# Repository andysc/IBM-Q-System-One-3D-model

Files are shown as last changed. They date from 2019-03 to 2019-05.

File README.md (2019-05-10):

# Quantum
3D-printed model of IBM Q System One

OpenSCAD model of a 1cm to 1foot scale model of the IBM Q System One Quantum Computer.

## Print list...
Set one of the control variables to *true* and all the others to *false* at the top of the model file to render each component in turn.

*black filament*
+ base
+ base_lid
+ back_box  * print with raft *  
+ top_box  
+ top_box_lid (inverted)   
+ lid (inverted)  
+ lid_lower (inverted)  
+ lid plinth (inverted for smoothness)   

*white filament*
+ reflector in white (inverted)  
+ reflector_strip in white

*translucent filament*
+ diffuser in clear filament (inverted)

Cryostat needs to be a 25mm x 44mm silver tube (I used chrome-plated wardrobe rail)

Glass walls in 1mm acrylic (2 of each size)  
front and back: 92 x 81 mm  
left and right: 85 x 81 mm

## Exploded view of the printed components

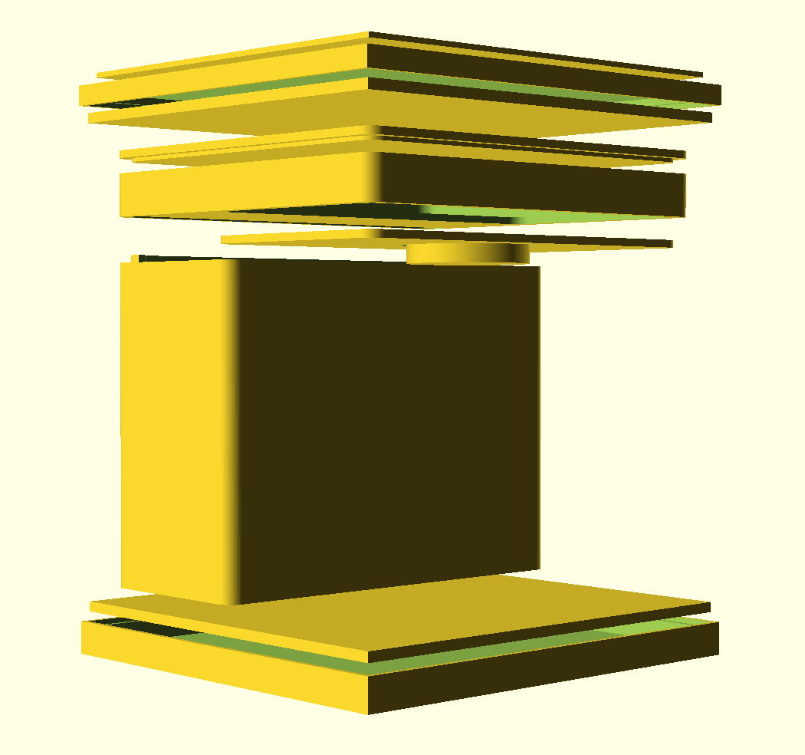
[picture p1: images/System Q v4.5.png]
exploded view


## The finished model

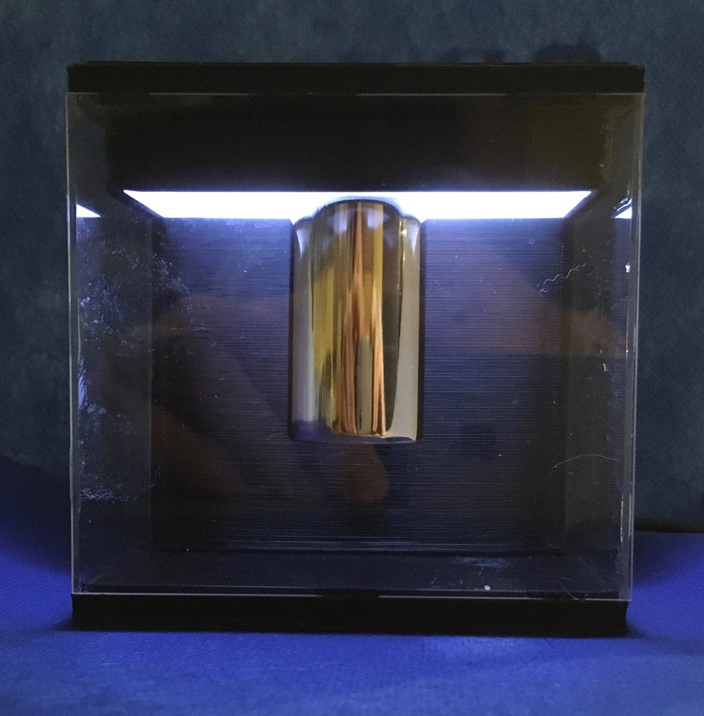
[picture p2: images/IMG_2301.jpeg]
IBM Q System One model


## Electronics

The top box has a row of 8 neopixels (144 leds/metre) inside, with a Wemos ESP-8266 Arduino (in the back box) controlling it via MQTT over WiFi. There's a cut-out for a micro-USB cable to come out through the back of the base.  

For information about how to connect a Wemos with Neopixels using MQTT, see @DrLucyRogers' excellent article here:
[Connect your IoT "Thing" to the Cloud](https://www.rs-online.com/designspark/content-types/project/13257?lang=en)

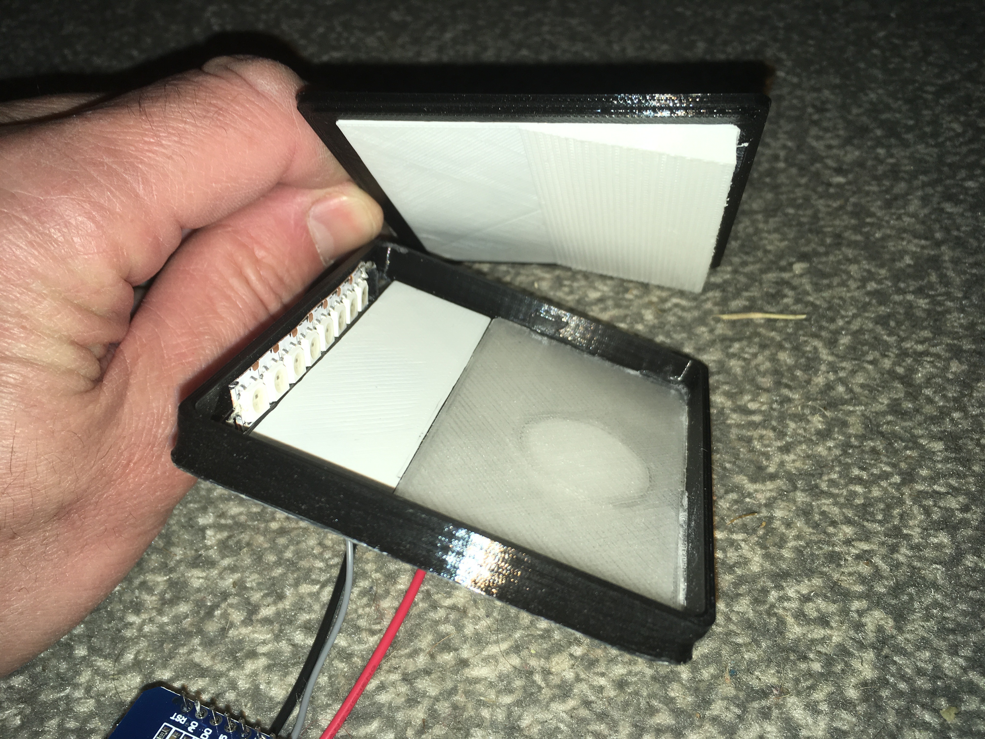
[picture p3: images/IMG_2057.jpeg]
top box detail


This is controlled by a node-red flow which controls the colours.

First it goes into a cool blue mode  

Then we run a Qiskit python script which connects to the real quantum computer (though the simulator takes much less time in the batch queue!), does a quantum coin flip, then returns an answer.

When we get the answer, we display a "superposed" state on the lights (red on one side and green on the other side, with a nice merge in the middle), pause for dramatic effect, then turn all red or all green, depending on whether it was heads or tails.

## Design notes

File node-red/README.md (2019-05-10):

Here's the flow for calling a python program to do the quantum coin flip, 
and controlling the LEDs on the model to show the funky blue while it's 
machinating, the superposed state (red AND green) then the outcome of the 
coin flip (red OR green).

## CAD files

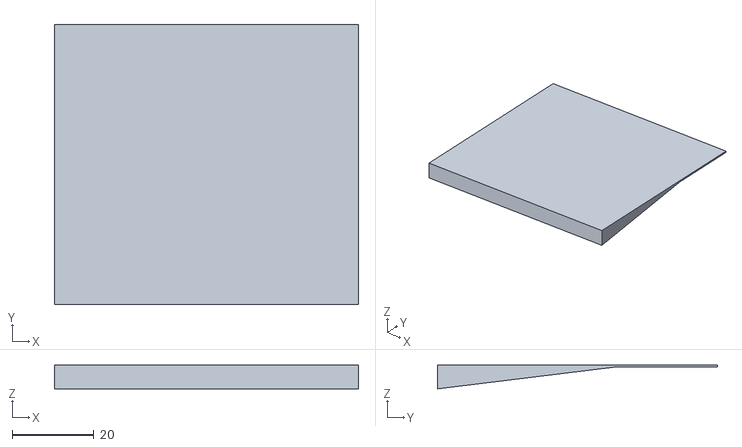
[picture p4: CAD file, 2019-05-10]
STL/reflector (white).stl
74.5 x 68.5 x 5.79

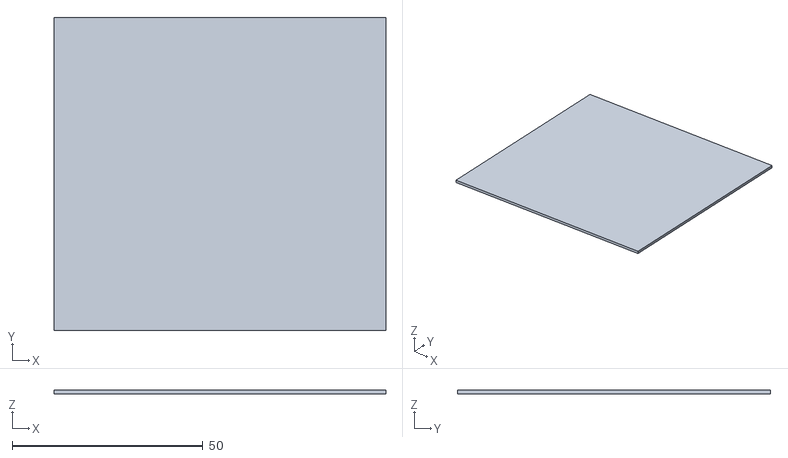
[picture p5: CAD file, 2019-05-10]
STL/lid_plinth.stl
87.0 x 82.0 x 1.00

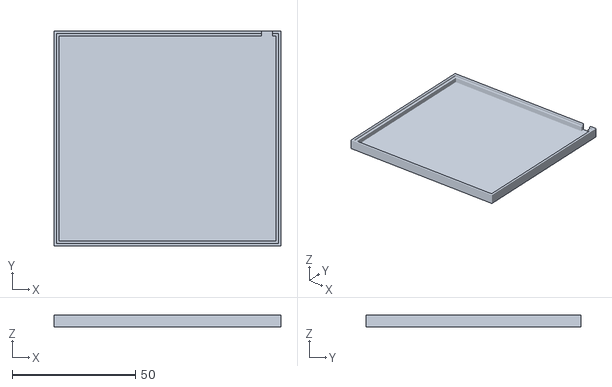
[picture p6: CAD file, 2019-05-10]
STL/base.stl
92.0 x 87.0 x 5.00

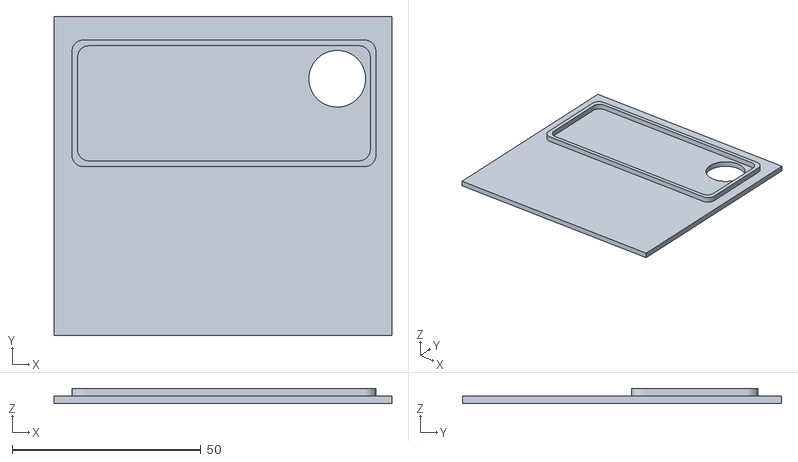
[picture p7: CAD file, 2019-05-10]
STL/base_lid.stl
89.5 x 84.5 x 4.00

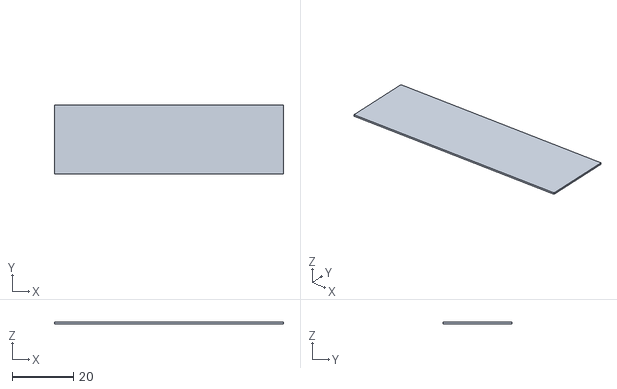
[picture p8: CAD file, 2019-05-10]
STL/reflector_strip (white).stl
74.5 x 22.4 x 0.5

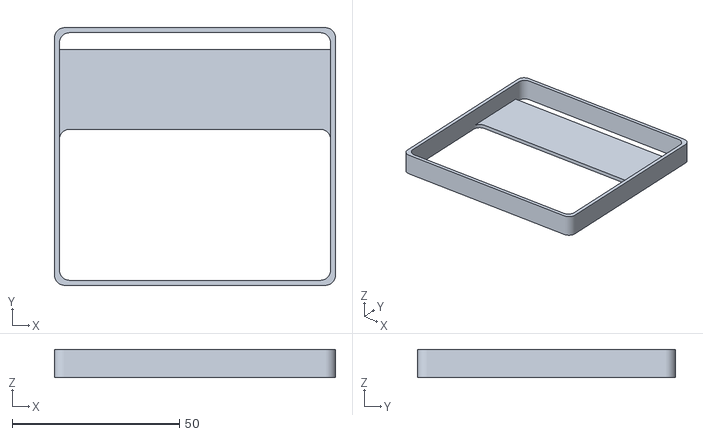
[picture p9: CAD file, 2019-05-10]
STL/top_box.stl
84.0 x 77.0 x 8.50

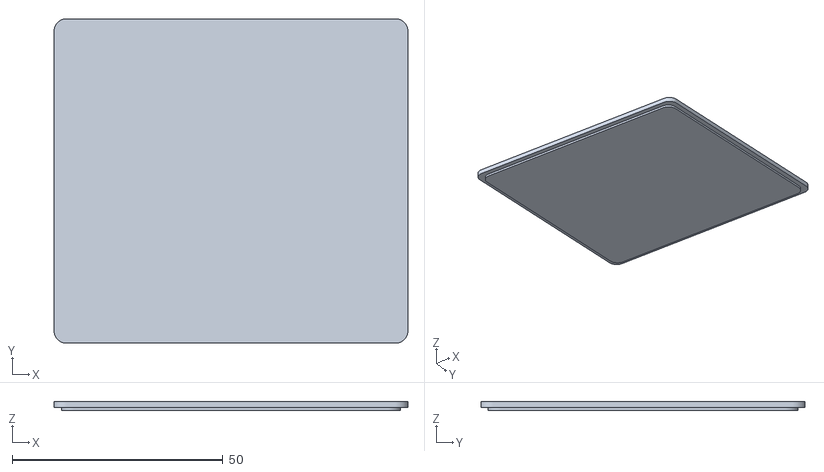
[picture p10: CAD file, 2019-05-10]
STL/top_box_lid.stl
84.0 x 77.0 x 2.25

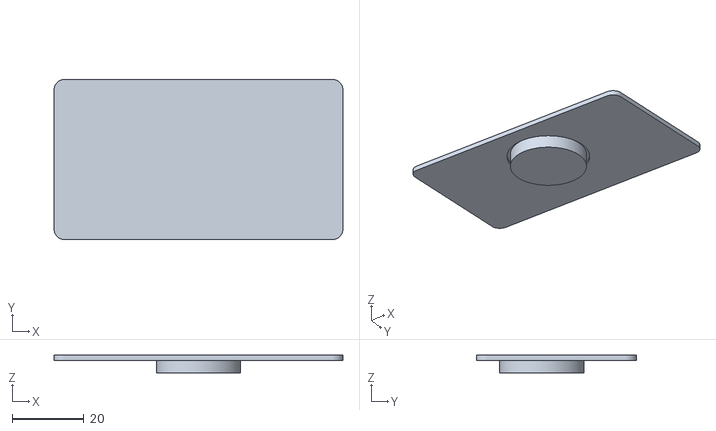
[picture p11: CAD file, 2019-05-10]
STL/diffuser (clear).stl
80.5 x 44.6 x 5.00

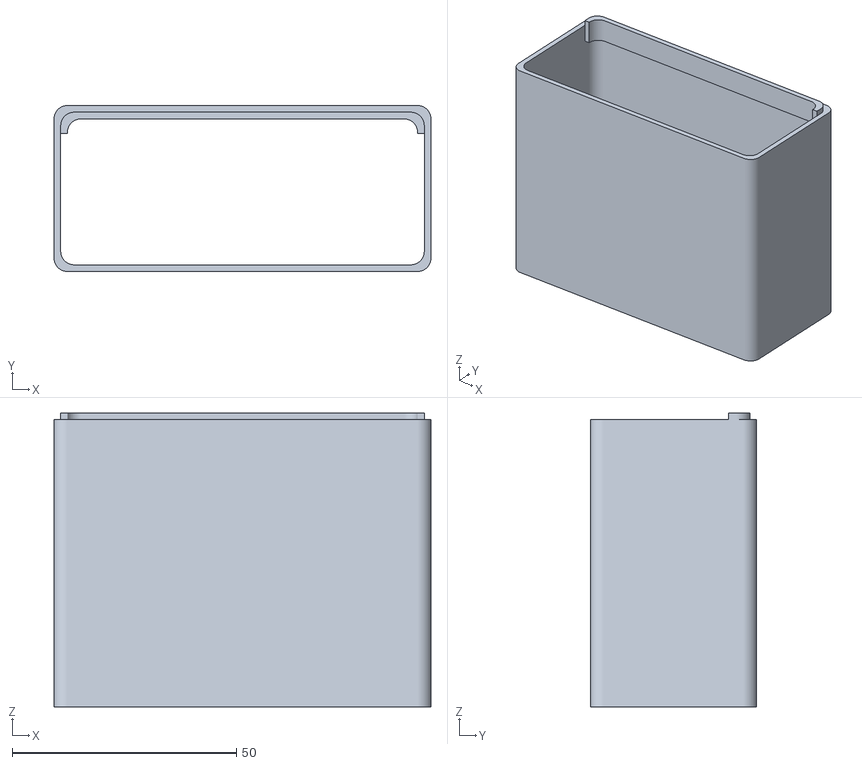
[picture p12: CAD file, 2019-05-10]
STL/back_box.stl
84.0 x 37.0 x 65.5

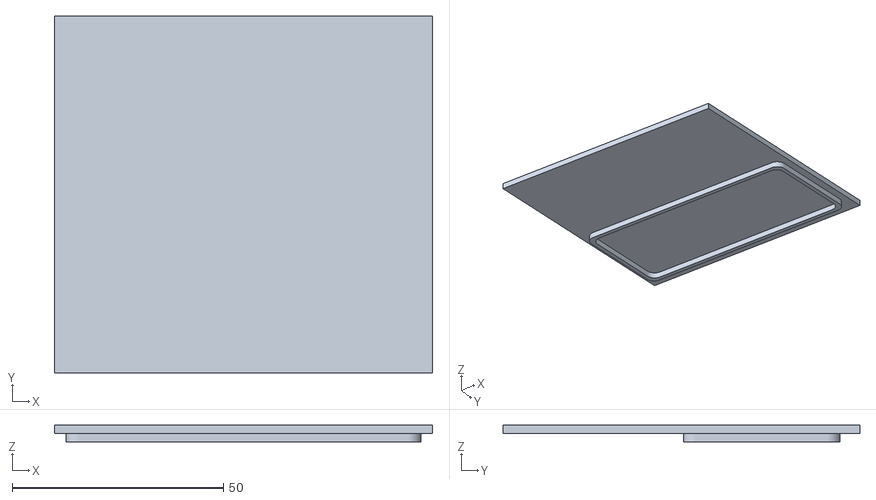
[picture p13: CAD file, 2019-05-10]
STL/lid_lower.stl
89.5 x 84.5 x 4.00

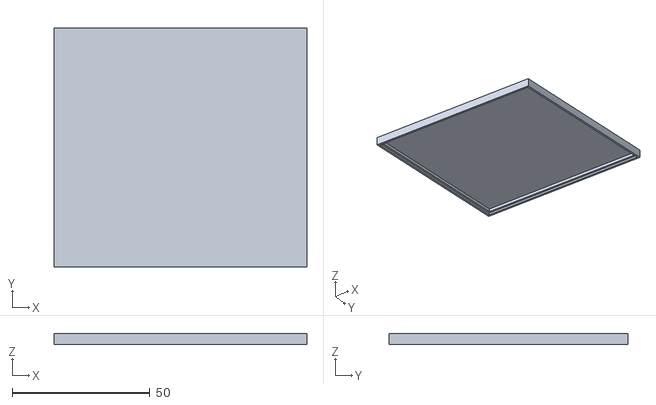
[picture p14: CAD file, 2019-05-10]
STL/lid.stl
92.0 x 87.0 x 4.00

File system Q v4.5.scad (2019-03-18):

// 1cm to 1foot scale model of the IBM Q System One Quantum Computer

// Andy Stanford-Clark
// andysc@uk.ibm.com / @andysc
// Feb '19


// v4.5 is a tidy-up for publication
// v4 is the redesigned glass idea for the base and lid
// v3 adds the deltas for the exploded view



// print list...

// 1. base 
// 2. base_lid 
// 3. back_box  * print with raft *
// 4. top_box * print with 1mm brim *
//    (then trim off all *except* the hole where the diffuser goes, as we need the lip to sit the diffuser on)
// 5. top_box_lid (inverted) 
// 6. lid (inverted)
// 7. lid_lower (inverted)
// 8. lid plinth (inverted for smoothness)

// 9. reflector in white (inverted)
// 10. reflector_strip in white

// 11. diffuser in clear filament (inverted) 

// cryostat needs to be a 25mm x 44mm silver tube (I used chrome-plated wardrobe rail)

// glass walls in 1mm acrylic
// front and back: 92 x 81 mm
// left and right: 85 x 81 mm 

// --------------------------------------------------------------------------------
// these should be the only bits you need to change (down to next dashed line)

// which bits to print?
// set each of these true in turn, and all the others false, to make each component


base = true;
base_lid = false;
back_box = false;
top_box = false;
top_box_lid = false;

// translucent
diffuser = false;

// white
reflector = false;
reflector_strip = false;

lid = false;
lid_lower = false; // the "lid" of the lid, if you like!
lid_plinth = false; // the thin plate on the very very top of the system


// --------------------------------------------------------------------------------
// optional elements for display purposes

cryostat = false; // we're not going to print this - it's just for display

// master control for walls
walls = false;
// selectively remove some of the walls
left_wall=true;
right_wall=false;
front_wall=false;
back_wall=true;


explode = 0; // set to 1 to explode the view, 0 normally

// --------------------------------------


wiring = true; // put in the cut-outs for a micro-USB cable
// how much extra height do we need on the base to allow for the cable?
extra_base = 1.5;


d = 3;
d1 = explode * d;     // base lid
d2 = explode * d*2; // back box
d3 = explode * d*5; // top box
d4 = explode * d*6.2; // lid lower
d5 = explode * d*7; // lid
d6 = explode * d*7.5; // lid plinth
d7 = explode * d*3; // diffuser 
d8 = explode * d*6; // top box lid
d9 = explode * d*2; // walls
d10 = explode * d*2; // cryostat


black = "white"; 
//black = "black";
white = "red";
//white = "white";

// going with a scale of 1cm to 1ft, so as it's 9ft wide, it's 90mm wide
// this is the INSIDE measurement - the flange for the glass is outside this
width = 90;
height = 90;
depth = 85;



mink_radius = 3;

// things that fit inside each other (e.g. diffuser inside top box)
// i.e. 0.5 mm total if you allow this each side (i.e. 2*)
tolerance = 0.25;

base_height = 6;
// make the back box a little bit lower just to allow for joint tolerances and stuff
back_box_height = 65 - 1; // this should be 65
back_box_depth = 37;   

top_box_height = 10;
// how far inset is the top box?
inside_gap = 3;

cryostat_height = 43;
cryostat_diameter = 25;

lid_height = 5;
// size of hole for wire in top box
wire_hole = 5;

// how thick to make the internal box walls
box_walls = 1.5;

// how thick is the half inch thick plate glass?
glass_thickness = 1;

// how thin to make the little outside lip of the base?
edge_delta = 0.5;
 
 
 
// here we go....  

back_box_width = width - 2*inside_gap;

color(black) {
    
// base
if (base) {
    difference() {
        translate([-glass_thickness, -glass_thickness, -extra_base])
            cube([width + 2*glass_thickness, depth + 2*glass_thickness, 
            base_height-1+extra_base]);
        // hollow out the insides
        translate([1, 1,-extra_base+box_walls])
            cube([width - 2, depth - 2, base_height-box_walls-1+extra_base]);
        // make a lip 1mm down for the lid to rest on
        translate([0, 0, base_height-1-1])
            cube([width, depth, 1]);
        
        // make the hole for the cable to come in
        if (wiring)
            translate([width - 7, depth -1, box_walls-extra_base])
                #cube([4.5,1+glass_thickness,base_height-box_walls-1+extra_base]);
        
    }  
}


// base lid
if (base_lid) {    
        difference() {
            union() {
                // lid panel
                translate([0,0,base_height-1-1 + d1])
                    cube([width-2*tolerance, depth-2*tolerance, 2]);
        
                // make a stub for the back box to sit over
                translate([inside_gap+mink_radius, inside_gap + (25+15) + mink_radius, base_height])
                // 1.5 * tolerance cos that's half of 3
                   translate([box_walls+1.5*tolerance, box_walls+1.5*tolerance, 0])
                        difference() {
                            minkowski() {
                                // make it 3*tolerance for a bit of extra wiggle room
                                cube([back_box_width-2*mink_radius - 2*box_walls - 3*tolerance, 
                                    back_box_depth-2*mink_radius - 2*box_walls - 3*tolerance, 
                                    2]);
                                // where '2' is the height of the stub
                                cylinder(r=mink_radius, h=0.0001, $fn=100);
                            }
                            // hollow out the inside
                            translate([box_walls, box_walls, 0])
                                minkowski() {
                                    cube([back_box_width-2*mink_radius - 2*box_walls - 2*tolerance - 2*box_walls, 
                                        back_box_depth-2*mink_radius - 2*box_walls - 2*tolerance - 2*box_walls, 
                                        2]);
                                    // where '2' is the height of the stub
                                    cylinder(r=mink_radius, h=0.0001, $fn=100);
                                }
                       } // difference
                   } // union
                   
        // make the hole for a cable to come in
        if (wiring) {
            // hole right through the base for micro USB plug to go through
            translate([inside_gap+mink_radius + back_box_width - 15, 
                        inside_gap + (25+15) + mink_radius + back_box_depth - 15,
                        0]) 
                cylinder(d=15, h=base_height, $fn=100);
 
        } // wiring
        
    }  // difference
}
    

// back box
if (back_box) {

  translate([inside_gap+mink_radius, inside_gap + 25+15 + mink_radius, base_height + d2]) {
 
    difference() {
        minkowski() {
            cube([back_box_width-2*mink_radius, back_box_depth-2*mink_radius, back_box_height]);
            cylinder(r=mink_radius, h=0.0001, $fn=100);
        }
        translate([box_walls, box_walls, 0])
            minkowski() {
                cube([back_box_width-2*mink_radius - 2*box_walls, 
                    back_box_depth-2*mink_radius - 2*box_walls, 
                    back_box_height+0.1]);
                cylinder(r=mink_radius, h=0.0001, $fn=100);
        }
    }
    
    // add a little lip for the top box to register onto
    translate([box_walls,back_box_depth - 2*mink_radius - wire_hole - box_walls,
        back_box_height - 5])
        difference() {    
            minkowski() {
                cube([width - 2*inside_gap - 2*mink_radius - 2*box_walls, 
                        wire_hole,
                    box_walls + 5]);
                cylinder(r=mink_radius, h=0.0001, $fn=100);
            }
            // take out the "inside"
                translate([box_walls,-box_walls,0])
                minkowski() {
                    cube([width - 2*inside_gap - 2*mink_radius - 2* 2*box_walls, 
                            wire_hole,
                        box_walls + 5]);
                    cylinder(r=mink_radius, h=0.0001, $fn=100);
                }
        // don't cut out a block the size of the minkowski radius added on top and bottom, 
        // so the hole is actually wire_holes mm across    
        translate([-mink_radius,-mink_radius,0])
            cube([width - 2*inside_gap - 0*2*mink_radius - 2*box_walls, 
            2*mink_radius + tolerance, box_walls + 5+0.1]);
        }
    }

}
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

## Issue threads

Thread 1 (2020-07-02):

Prusa Slic3r: Hollowing leads to bridge infill

BAndiT1983, 2020-07-02:
Hi,
while trying to print the model, some strange rips occurred. After inspecting the layers in Prusa Slic3r again, I've noticed that bridge infills are created over the whole model diagonally, which results in ripping up, as the material is not connected to anything below and the heat twists the bridges.

Looked at SCAD file and seen that it hollows the parts out. Could you provide a version, without hollow inside, please?

andysc, 2020-07-02:
Hi - it's meant to be hollow, and printed in lots of different bits and then assembled.
There's a printing schedule which lists all the STLs that need to be printed.
Are you trying to print the whole model in one go?

BAndiT1983, 2020-07-02:
No, not as whole. What i meant about hollow, the insides of individual parts as lid or base. It looks like the insides are not there, so the slicer plans bridge infills and not proper infill like gyroid, grid etc.

andysc, 2020-07-02:
OK - let's talk about one STL in particular, so we're on the same page... lid.stl ?
that is meant to be hollowed-out, as the wire runs through it, and base_lid clips into the top.
You have to flip it over so it's "bottom-down", of course.
What is the STL file you posted the photo of?

BAndiT1983, 2020-07-02:
The STL was flipped (am not new to 3D printing), as there is not much point to print it upside down and having a lot of supports and coarse surface.

File could be lid.stl, but all 4 are looking similar (besides one with the hole), as there was collision detected and printer stopped, so cannot distinguish them that much.

andysc, 2020-07-02:
In that case I'm not sure what you're asking me to fix?
A flat panel is a flat panel, made with "cube" in openSCAD, so it's not hollow "inside" (your slicer does whatever it needs to for internal infill).
And a "box" (like lid.stl) that's hollowed-out should have "nothing" in the empty inside (as we subtract a cube from the solid block we started with), so that shouldn't cause any artefacts in the STL, and I haven't seen that happen anywhere else these have been printed.

BAndiT1983, 2020-07-02:
Ok, then, then i will continue to search for some solution myself. Never had a problem with my printer before and mostly printing my own stuff, which was done in Fusion360.

Also not sure why the model needs that many parts to print, so will possibly recreate it differently for my needs.

andysc, 2020-07-02:
I'd be interested to know why it's doing this. I'll see if I can find someone else with a Prusa to try it.

And yes, if you'd like to make a version with fewer parts, that would be great.

I have electronics in various places, so need the internal spaces. I guess the base could be one piece, but I wanted to hide the wire.
The very top box ("lid") (above the light box) is hollow in anticipation of v2 which has an OLED display at the top.
And the back box has a Raspberry PiZeroW inside... so there isn't much reduction of parts that can be done for my needs.

BAndiT1983, 2020-07-02:
Have checked Prusa forum, also related SCAD issues and disabled "Ensure vertical shell thickness" option, with this the bridge infills are gone, the object is solid now, as it's rather thin by itself. The downside there is the long printing time, although the infill is set to 20%, but not used, slicer says 4h 8m for lid, lid_lower, base and base_lid.

The project was forwarded to me by someone who works at IBM and i was asked to print it. So the interest to replicate it and possibly improve is there.

andysc, 2020-07-02:
That seems a reasonable time to print all of those (I assume it's together, not each) :)

I'm surprised the infill "spills out" onto the top - surely it should all stay inside...
what size nozzle are you using?

How thin is "rather thin" in your book?
I see lid_lower and base_lid are 4mm thick (maybe a bit excessive with hindsight) - I would have thought the infill algorithm should be able to deal with that... I use 30% infill (the default) on mine.

If the someone who works at IBM wants to contact me, they're very welcome to :)

BAndiT1983, 2020-07-02:
Usually it should print faster if there is infill and not solid layer, at least from my experience. But with 0.2mm layer height, there are only 6 layers or so and that i would consider as rather thin. Referring solely to the base of the lid, without considering the walls.

The infill is not used, as shell thickness is set to 2 by default. Have to play around with print settings a bit more, it could help to accelerate this. Usually printing a lot faster, especially with gyroid infill.

Using standard 0.4mm nozzle on the Prusa MK3S.

Will forward your message to the person.

andysc, 2020-07-02:
OK - I *do* assume infill ... it's just a default on my slicer. Perhaps I should mention that in the notes.
But then I can see how shell thickness could get in the way of that on yours... is that "2" mm or layers?

BAndiT1983, 2020-07-02:
The 2 is referring to layers here, seen also that there are more layers set for the bottom on different presets, like 4, before it starts to add infill, will check it a bit later. Am adjusting settings only when required, e.g. printing something a bit more complicated. Usually Prusa presets are rather to the point for me, even for such stuff like nut/screw pockets.

Closed 2020-07-02.

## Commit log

2019-03-16 Create system Q v4.5.scad
    [system Q v4.5.scad]
2019-03-16 Update system Q v4.5.scad
    [system Q v4.5.scad]
2019-03-16 fixed diffuser position in exploded view
    [system Q v4.5.scad]
2019-03-18 last change was improve printability of top_box
    Having trouble with warping, so changed to print with brim, and then cut off excess, apart from in the diffuser hole, where it forms the lip the diffuser sits on.
    [system Q v4.5.scad]
2019-05-10 added new files
    [back_box.stl, base.stl, base_lid.stl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]
